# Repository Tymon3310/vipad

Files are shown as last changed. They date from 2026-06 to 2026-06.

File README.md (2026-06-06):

# vipad
vipad is a 4x4 macropad powered by vial firmware

It also has 2 encoders (knobs), oled screen and rgb leds

Overall render:

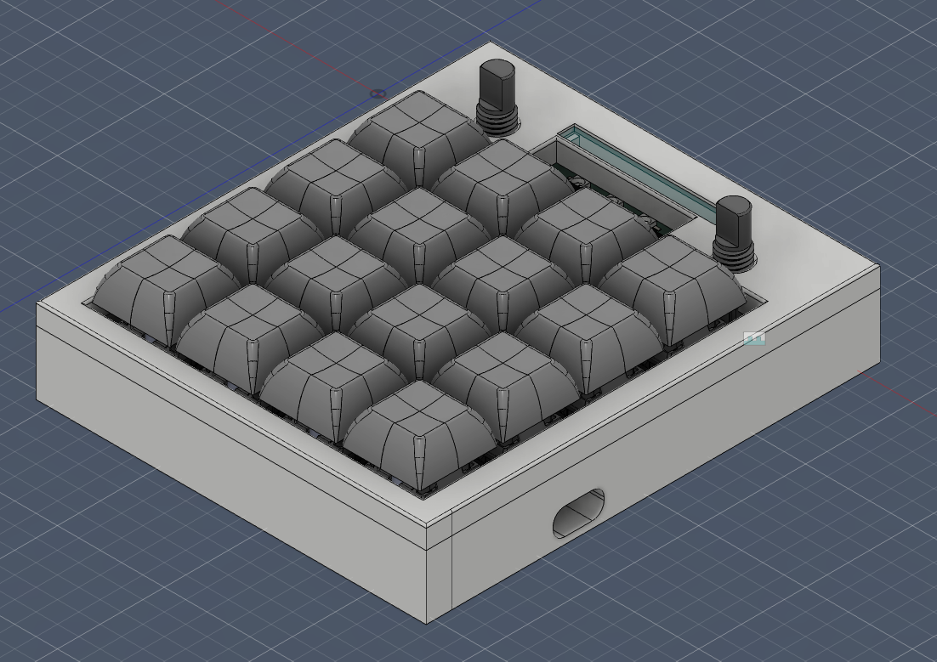
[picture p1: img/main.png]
Overall render


Schematics:

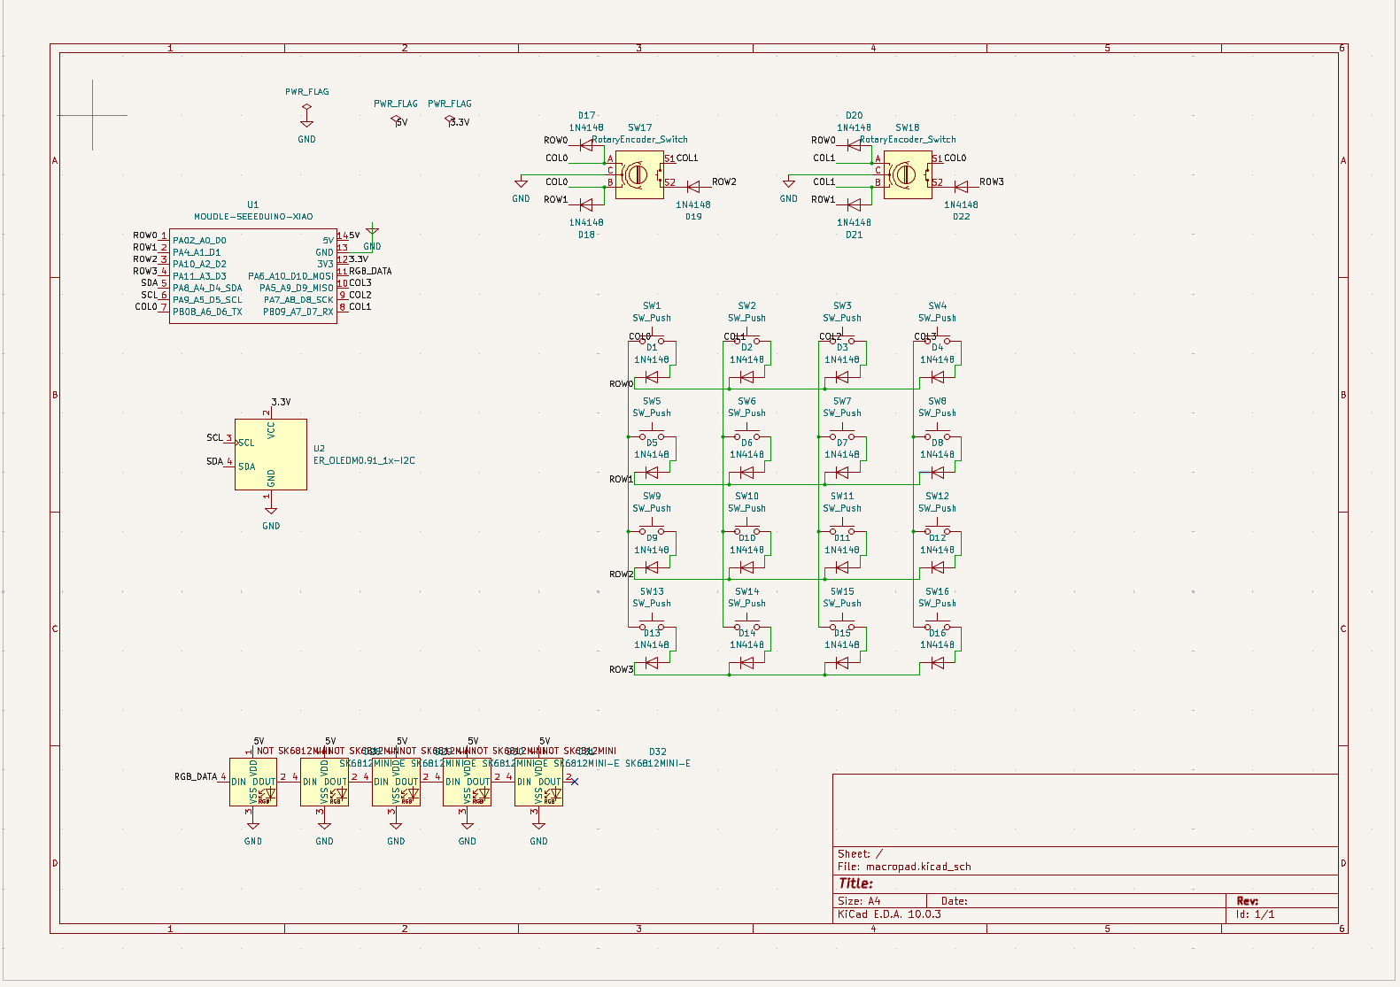
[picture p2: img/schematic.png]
Schematics


PCB:

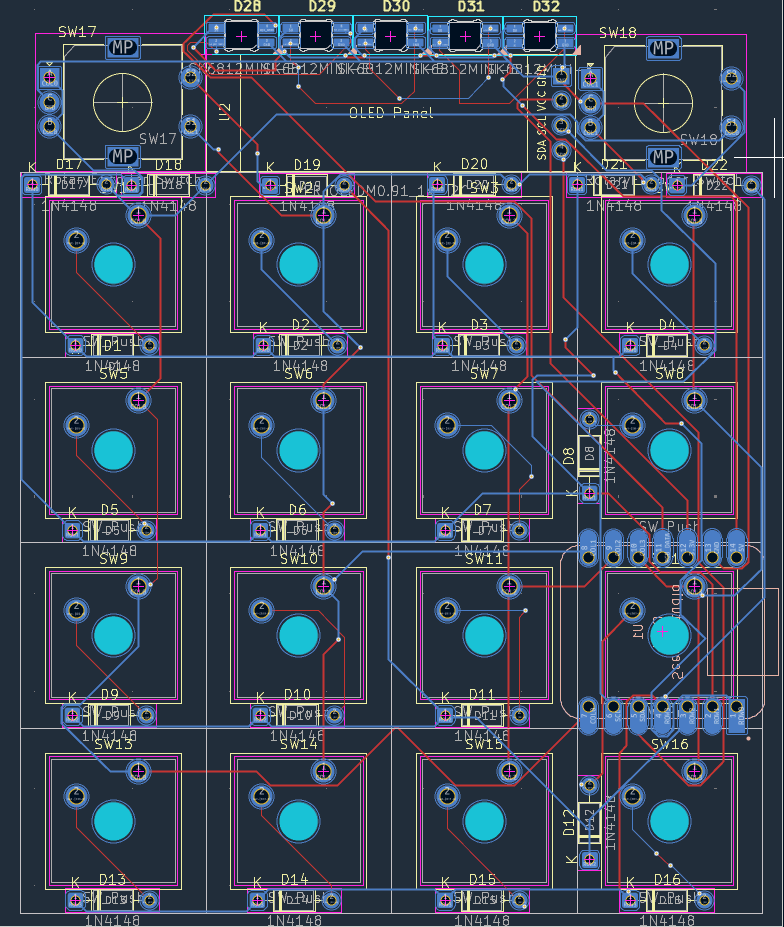
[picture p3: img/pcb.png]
PCB view


Bill of materials:
- 1 custom pcb
- 16 MX-style mechanical switches
- 16 Blank DSA keycaps
- 2 EC11 rotary encoders
- 1 0.91” 128×32 OLED display
- 1 case (top and bottom)
- 1 Seeed XIAO RP2040
- 22 1N4148 diodes
- 5 SK6812 MINI-E RGB LEDs
- 6 M3×16mm screws
- 6 M3×5×4mm heatset inserts

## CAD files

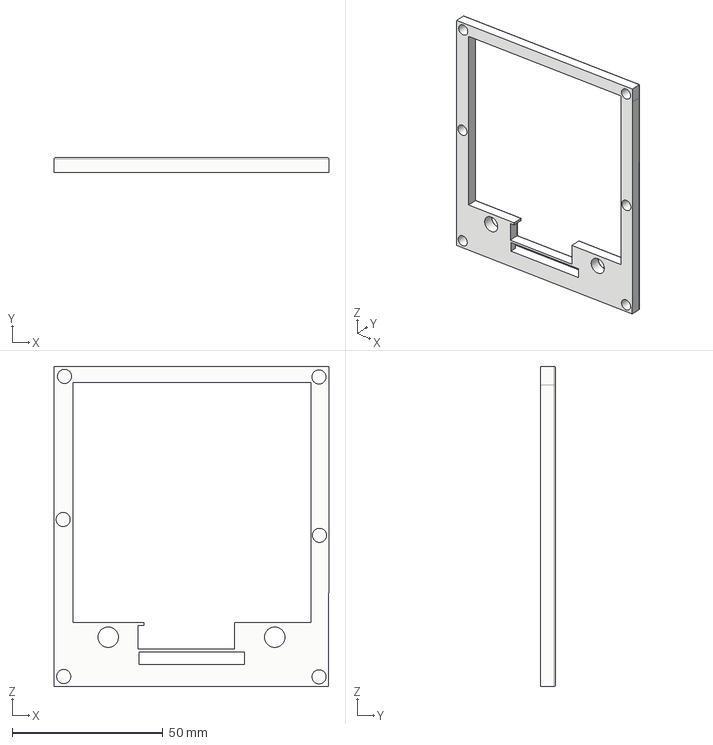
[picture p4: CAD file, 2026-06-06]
production/top.step
91.2 x 5.00 x 106.3 mm

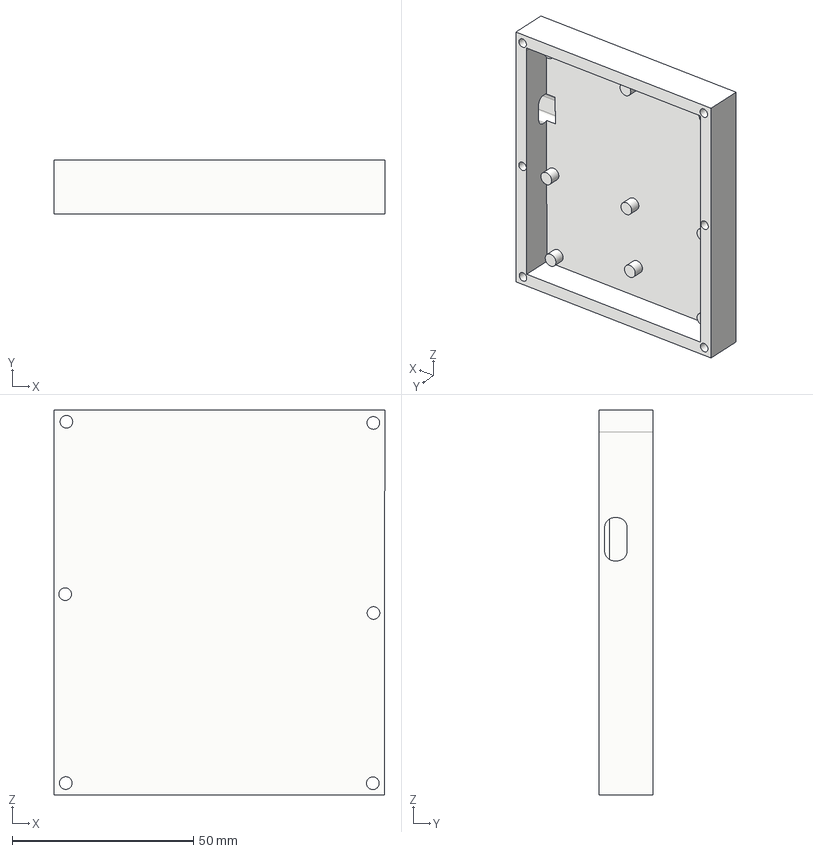
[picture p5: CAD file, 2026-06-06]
production/bottom.step
91.2 x 15.0 x 106.3 mm

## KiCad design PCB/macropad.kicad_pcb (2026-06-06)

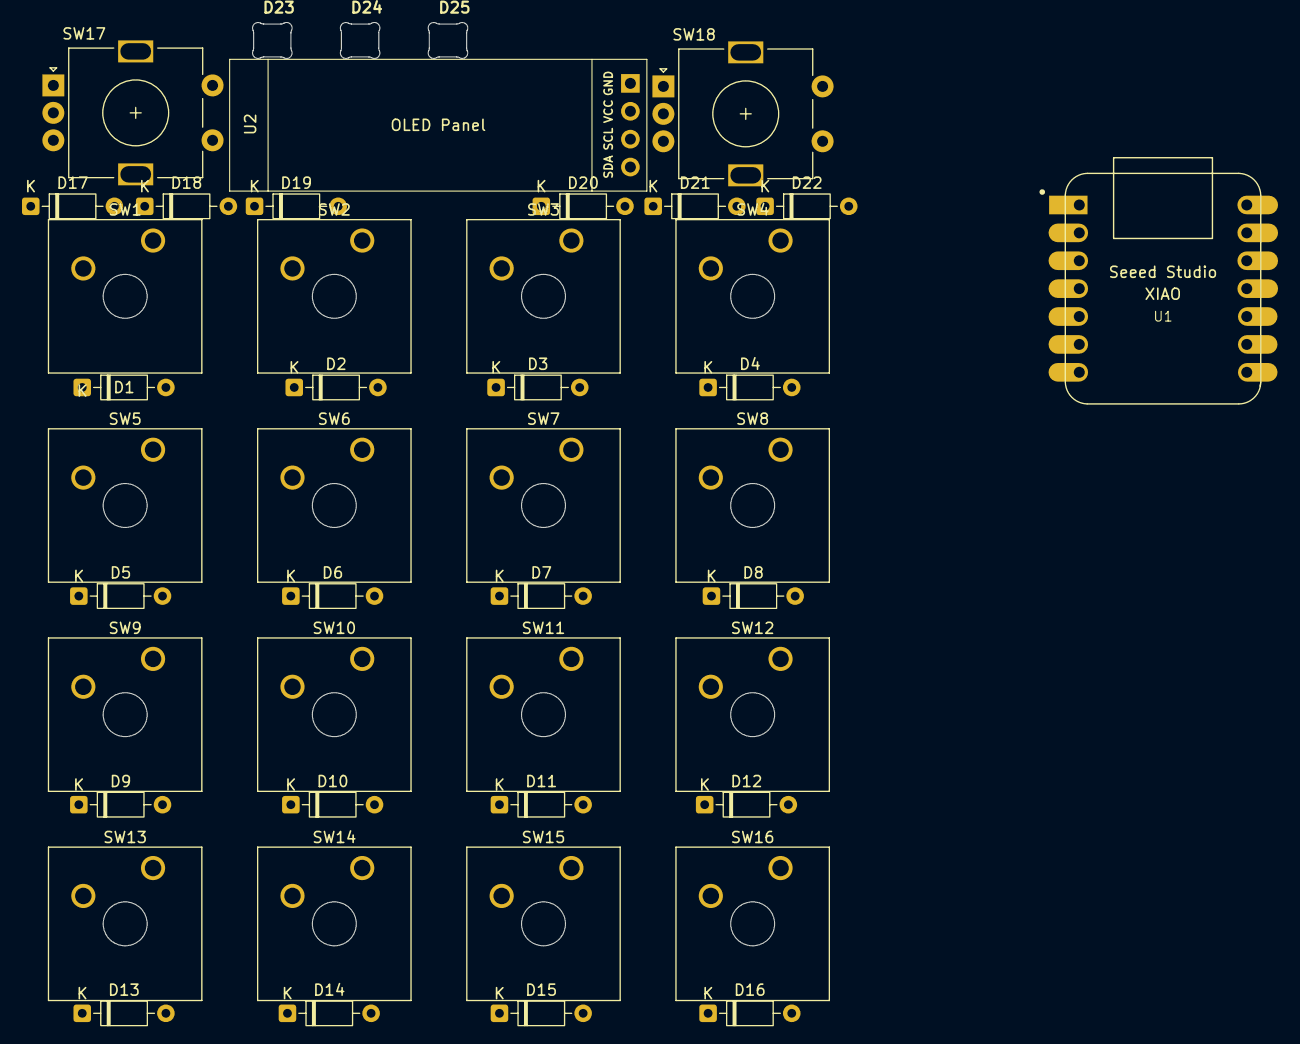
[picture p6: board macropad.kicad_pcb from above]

Board: 2 copper layers, 45 parts (0 on the bottom side), 32 nets, no tracks yet.

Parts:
D1, D2, D3, D4, D5, D6, D7, D8, D9, D10, D11, D12, D13, D14, D15, D16, D17, D18, D19, D20, D21, D22: 1N4148; D_DO-35_SOD27_P7.62mm_Horizontal
D23, D24, D25: SK6812MINI-E; SK6812MINI-E_fixed
SW1, SW2, SW3, SW4, SW5, SW6, SW7, SW8, SW9, SW10, SW11, SW12, SW13, SW14, SW15, SW16: SW_Push; SW_Cherry_MX_1.00u_Plate
SW17, SW18: RotaryEncoder_Switch; RotaryEncoder_Alps_EC11E-Switch_Vertical_H20mm
U1: MOUDLE-SEEEDUINO-XIAO; XIAO-Generic-Hybrid-14P-2.54-21X17.8MM
U2: ER_OLEDM0.91_1x-I2C; SSD1306-0.91-OLED-4pin-128x32

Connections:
/3.3V: U1.12 (3V3), U2.2 (VCC)
/5V: D23.1 (VDD), D24.1 (VDD), D25.1 (VDD), U1.14 (5V)
/COL0: D17.2 (A), D18.2 (A), SW1.1, SW5.1, SW9.1, SW13.1, SW17.A, SW17.B, SW18.S1, U1.7 (PB08_A6_D6_TX)
/COL1: D20.2 (A), D21.2 (A), SW2.1, SW6.1, SW10.1, SW14.1, SW17.S1, SW18.A, SW18.B, U1.8 (PB09_A7_D7_RX)
/COL2: SW3.1, SW7.1, SW11.1, SW15.1, U1.9 (PA7_A8_D8_SCK)
/COL3: SW4.1, SW8.1, SW12.1, SW16.1, U1.10 (PA5_A9_D9_MISO)
/RGB_DATA: D23.4 (DIN), U1.11 (PA6_A10_D10_MOSI)
/ROW0: D1.1 (K), D2.1 (K), D3.1 (K), D4.1 (K), D17.1 (K), D20.1 (K), U1.1 (PA02_A0_D0)
/ROW1: D5.1 (K), D6.1 (K), D7.1 (K), D8.1 (K), D18.1 (K), D21.1 (K), U1.2 (PA4_A1_D1)
/ROW2: D9.1 (K), D10.1 (K), D11.1 (K), D12.1 (K), D19.2 (A), U1.3 (PA10_A2_D2)
/ROW3: D13.1 (K), D14.1 (K), D15.1 (K), D16.1 (K), D22.2 (A), U1.4 (PA11_A3_D3)
/SCL: U1.6 (PA9_A5_D5_SCL), U2.3 (SCL)
/SDA: U1.5 (PA8_A4_D4_SDA), U2.4 (SDA)
GND: D23.3 (VSS), D24.3 (VSS), D25.3 (VSS), SW17.C, SW18.C, U1.13 (GND), U2.1 (GND)
unnamed: D1.2 (A), SW1.2
unnamed: D2.2 (A), SW2.2
unnamed: D3.2 (A), SW3.2
unnamed: D4.2 (A), SW4.2
unnamed: D5.2 (A), SW5.2
unnamed: D6.2 (A), SW6.2
unnamed: D7.2 (A), SW7.2
unnamed: D8.2 (A), SW8.2
unnamed: D9.2 (A), SW9.2
unnamed: D10.2 (A), SW10.2
unnamed: D11.2 (A), SW11.2
unnamed: D12.2 (A), SW12.2
unnamed: D13.2 (A), SW13.2
unnamed: D14.2 (A), SW14.2
unnamed: D15.2 (A), SW15.2
unnamed: D16.2 (A), SW16.2
unnamed: D19.1 (K), SW17.S2
unnamed: D22.1 (K), SW18.S2

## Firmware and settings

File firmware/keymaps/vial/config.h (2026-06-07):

/* SPDX-License-Identifier: GPL-2.0-or-later */

#pragma once

#define VIAL_KEYBOARD_UID {0x5A, 0x42, 0xC3, 0x19, 0x8E, 0x4F, 0x22, 0xD7}

// disable for now
// #define VIAL_UNLOCK_COMBO_ROWS { 0, 0 }
// #define VIAL_UNLOCK_COMBO_COLS { 0, 1 }

#define I2C_DRIVER          I2CD1
#define I2C1_SDA_PIN        GP6
#define I2C1_SCL_PIN        GP7

#define OLED_DISPLAY_128X64
#define OLED_TIMEOUT        60000

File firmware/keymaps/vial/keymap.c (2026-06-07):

/* SPDX-License-Identifier: GPL-2.0-or-later */

#include QMK_KEYBOARD_H

const uint16_t PROGMEM keymaps[][MATRIX_ROWS][MATRIX_COLS] = {
    [0] = LAYOUT(
        KC_7, KC_8, KC_9, KC_ASTR,
        KC_4, KC_5, KC_6, KC_SLSH,
        KC_1, KC_2, KC_3, KC_MINS,
        KC_0, KC_DOT, KC_ENT, KC_PLUS),
    [1] = LAYOUT(
        KC_TRNS, KC_TRNS, KC_TRNS, KC_TRNS,
        KC_TRNS, KC_TRNS, KC_TRNS, KC_TRNS,
        KC_TRNS, KC_TRNS, KC_TRNS, KC_TRNS,
        KC_TRNS, KC_TRNS, KC_TRNS, KC_TRNS)};

#if defined(ENCODER_MAP_ENABLE)
const uint16_t PROGMEM encoder_map[][NUM_ENCODERS][2] = {
    [0] = {
        ENCODER_CCW_CW(KC_VOLD, KC_VOLU),
        ENCODER_CCW_CW(KC_MS_WH_UP, KC_MS_WH_DOWN)},
    [1] = {ENCODER_CCW_CW(KC_TRNS, KC_TRNS), ENCODER_CCW_CW(KC_TRNS, KC_TRNS)}};
#endif

#ifdef OLED_ENABLE
bool oled_task_user(void)
{
    oled_write_P(PSTR("Pad: Vipad\n"), false);
    oled_write_P(PSTR("Layer: "), false);

    switch (get_highest_layer(layer_state))
    {
    case 0:
        oled_write_P(PSTR("BASE (NUM)\n"), false);
        break;
    case 1:
        oled_write_P(PSTR("FN (MEDIA)\n"), false);
        break;
    default:
        oled_write_P(PSTR("CUSTOM\n"), false);
    }

    oled_write_P(PSTR("\nEnc1: Vol\nEnc2: Scroll"), false);

    return false;
}
#endif
